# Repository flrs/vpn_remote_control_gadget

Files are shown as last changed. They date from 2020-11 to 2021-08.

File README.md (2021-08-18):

# VPN Remote Control Gadget

> Make it easy to be more private on the internet and remote control the VPN settings on your ASUS RT-AC68U router.

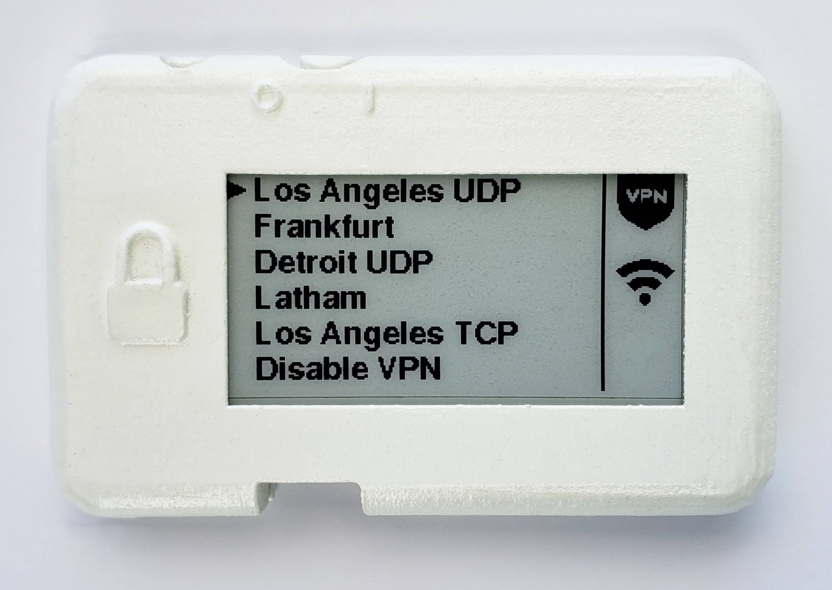
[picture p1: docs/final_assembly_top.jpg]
VPN Remote Control Gadget Case
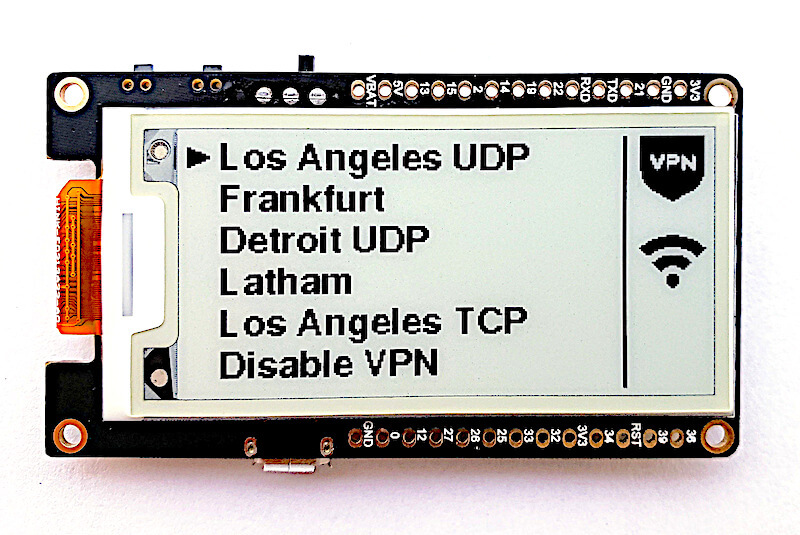
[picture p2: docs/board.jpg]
VPN Remote Control Gadget Without Case


This project creates a remote control from the Arduino-programmed LilyGo TTGO T5 V2.3 ESP32 e-paper microcontroller 
board and a custom-designed 3D-printed case.

## Getting Started

Here is what you will need to build this project yourself:
- ASUS RT-AC68U router, configured to use a VPN of your choice
- LilyGo TTGO T5 V2.3 board
- USB charger and/or small LiPo battery (look for model number 301525)

### Programming the TTGO T5

You can find the Arduino sketch in the [vpn_remote_control_gadget](./arduino/vpn_remote_control_gadget) directory. 

1. Copy this directory into your Arduino sketch directory.
2. Follow the instructions in the 
   [LilyGo repository](https://github.com/Xinyuan-LilyGO/LilyGo-T5-ink-series/tree/acffc2fce8a6d504aa812ce1f9745281bd57a4bc)
   to install Arduino libraries for the TTGO T5 V2.3 board.
3. Install the following Arduino libraries via the Arduino library manager:
   - [ArduinoHttpClient](https://github.com/arduino-libraries/ArduinoHttpClient/tree/7f36561e0bced5458516066ae09636e119cae0ed)
   - [rBASE64](https://github.com/boseji/rBASE64/tree/a127f41eea31d2de7abc91cff4b2d1f4521625ec)
   - [ArduinoJson](https://arduinojson.org/)
   - [StringSplitter](https://github.com/aharshac/StringSplitter/tree/faef239fcea57055ba7bddc35d4a6c47bc05a9b4)
4. Modify the credentials in file [credentials_template.h](./arduino/vpn_remote_control_gadget/credentials_template.h) 
   and rename the file to `credentials.h`.
5. Upload the sketch to the board!

### Printing the Case

Send the file [vpn_control_gadget_assembly_manuf.obj](./cad/manufacturing/vpn_remote_control_gadget_assembly_manuf.obj)
to a 3D printing place of your choice. The case is designed so it can be printed through SLS with PA 12 material and a
rough finish. A [vpn_control_gadget_assembly_manuf.stl](./cad/manufacturing/vpn_remote_control_gadget_assembly_manuf.stl)
file is also available, should your printing place not like `.obj` files.

## Using the Gadget

To select a new VPN server or disconnect from the VPN, turn the TTGO T5 on using the slider on top of the case. Then,
select a VPN with the button next to the slider. Once the checkmark appears in the bottom right of the screen, the
request to change the VPN has been sent to the router. Now, you can turn off the gadget with the slider again. This 
helps to save battery. 

Thanks to the e-paper display your choice will remain visible even when the device powers off.

## Code Overview

The code on the Arduino talks to the ASUS router via POST requests. This is just like how the browser communicates with
the ASUS configuration page when you are logged into the router configuration in your browser.

The code was only tested with RT-AC68U firmware version 3.0.0.4.385_20633. If you use a different firmware, this code
may not longer work without adjustments.

All icons in the UI except for the arrow have been downloaded from [flaticon.com](https://www.flaticon.com) and 
converted to an Arduino-readable file format via the [LCD Image Converter](https://lcd-image-converter.riuson.com).

## CAD Overview

(see also on [Thingiverse](https://www.thingiverse.com/thing:4668495))

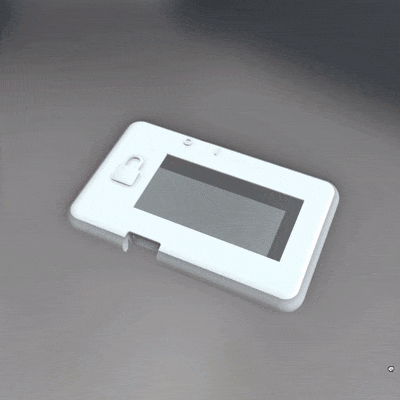
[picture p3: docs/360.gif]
360 degree view of CAD assembly


If you want to modify the case, you can find all CAD design files in the [cad/design](./cad/design) directory. You can
open and edit the files in [FreeCAD](https://www.freecadweb.org/). The files were created in FreeCAD version 0.19-22492.

### Mechanical Features

**Lid:** The case has a sliding lid on the back through which the microcontroller board can be inserted and removed. 
The lid is held in place by a pin. The pin unlocks when the lid is bent outward.

**Buttons:** The case has interfaces to 2 of TTGO T5's buttons. The lid features a cover for the button that is 
connected to channel IO39. The cover is connected to the case by a living hinge, avoiding any additional assembly. 
The case also provides an interface for the board's on/off slider. The slider is a removable part of the assembly, 
but stays in place thanks to a groove in the case's body once the board is assembled.

### Assembly Notes

With the case, the TTGO T5 can be either used with a USB connection alone, or with a small LiPo battery. There is space 
for a 80 mAh battery in the case (search for model number 301525).

There are 6 cylindrical support pins that help the assembly stay in placing during printing. After printing, you need 
to remove these 6 pins to separate the model into its 3 parts. If printed with PA 12, these pins should be easy to cut 
with scissors, a knife, or simply bending until they break. To make sure all components slide and fit neatly, you should
 grind down any leftovers of the pins.

Once all components are separated, push the on/off slider component onto the on/off switch, insert the board into to 
case, and slide the lid shut.

Optionally, the case can be mounted on surfaces by means of double-sided tape.

## Potential Design Improvements

The design presented here is functional. However, based on feedback from the very first 3d print of the gadget 
(see make on [Thingiverse](https://www.thingiverse.com/make:906624)), there are a couple of improvements future makers
may want to take on:

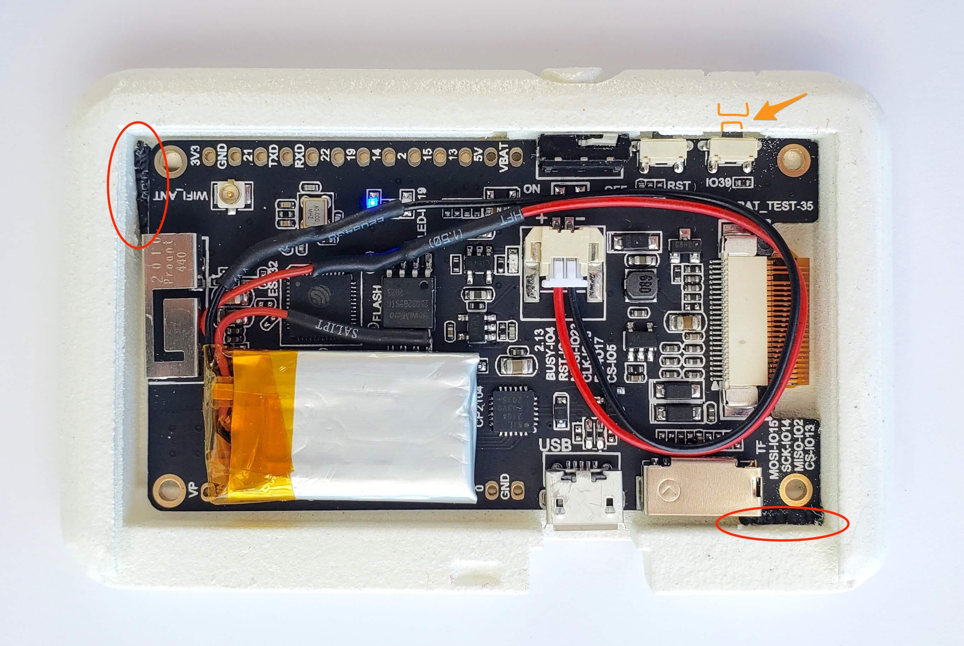
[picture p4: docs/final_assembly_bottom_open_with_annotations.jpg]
VPN Remote Control Gadget bottom, open cover, with annotations


- **Tolerances of part are too large.** During design, I was extra cautious to implement a +0.5 mm tolerance in all directions. 
This creates gaps that are too large, resulting in the PCB in the case sliding around and the slider originally not working. Filling material 
gets the job of fixing the PCB done and makes the slider workable (see red ellipses). Before printing, I 
would advise makers to add about 0.4 mm to the inner walls to restrict lateral movement of the PCB. Also consider that 
this may bring the e-paper screen further off-center, potentially hiding part of the screen.

- **Pushbutton casing component not properly dimensioned.** The gap between the lower side of the case's pushbutton 
component is too far from the top of the actual pushbutton. This results in the user having to press the push button 
in the casing with a lot of force for the actual pushbutton to be actuated. I would advise adding about 0.5 mm to 
the inner-facing part of the push button component in the casing before printing (see orange arrow).

- **USB interface slot slightly misaligned.** The USB interface slot should be positioned a little bit more (about
 0.5 mm) to the left, looking from the bottom of the case, as in the picture above. While the current position works
 for connecting a USB charger, it is slightly off-center.

- **Case cover too thin.** The sliding case cover, while functional, is subjectively too thin. It bends, making it 
hard for the pin that goes into the groove for closing the cover to stay in place. For future iterations, I 
would advise to deepen the groove for closing and to make the pin bigger. I would also advise to increase the 
thickness of the cover. Alternatively, I would add structural elements to the underside of the cover to improve its stiffness.

## Contributing

For questions or feedback, please file an issue here on GitHub. Feel free to open pull requests for any changes you 
think the project could benefit from.

## Credits

Code:
 - Used LilyGO [starter sketch](https://github.com/Xinyuan-LilyGO/LilyGo-T5-ink-series/blob/acffc2fce8a6d504aa812ce1f9745281bd57a4bc/LilyGo_T5_V2.3/LilyGo_T5_V2.3.ino) as a basis for communicating with e-paper display
 - WiFi Error icon, WiFi icon, VPN, and tick icon made by [Freepik](https://www.flaticon.com/authors/freepik) from [www.flaticon.com](https://www.flaticon.com/)
 - Hourglass icon made by [Kiranshastry](https://www.flaticon.com/free-icon/hourglass_709705?term=hourglass&page=1&position=18&related_item_id=709705) from [www.flaticon.com](https://www.flaticon.com/)

CAD:
 - The eye illustration on the back of the lid is part of Samuel Jessurun de Mesquita's print 
   "Zelfportret van alleen de ogen" (public domain, see [here](http://hdl.handle.net/10934/RM0001.COLLECT.209046)).

## License

This project is published under the [MIT License](./LICENSE.md).

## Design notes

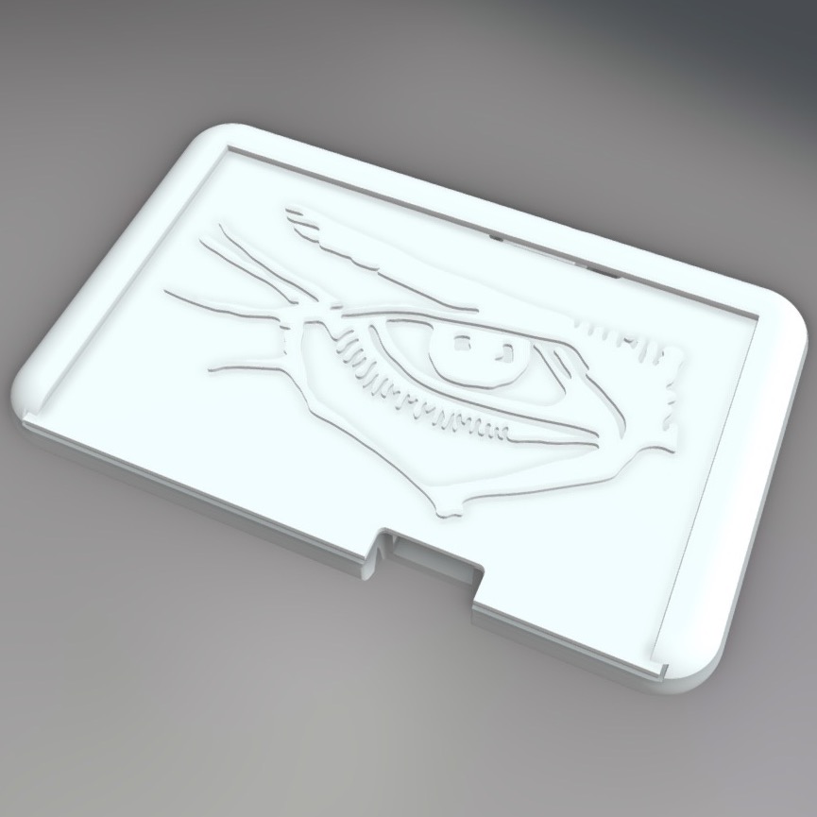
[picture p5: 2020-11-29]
docs/back.jpg

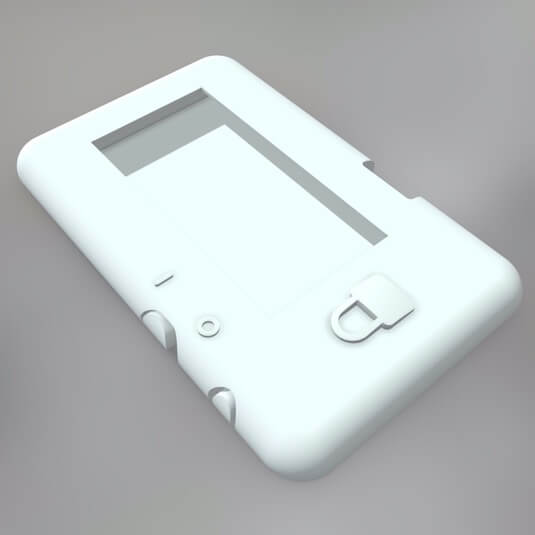
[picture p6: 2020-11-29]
docs/front_smaller.jpg

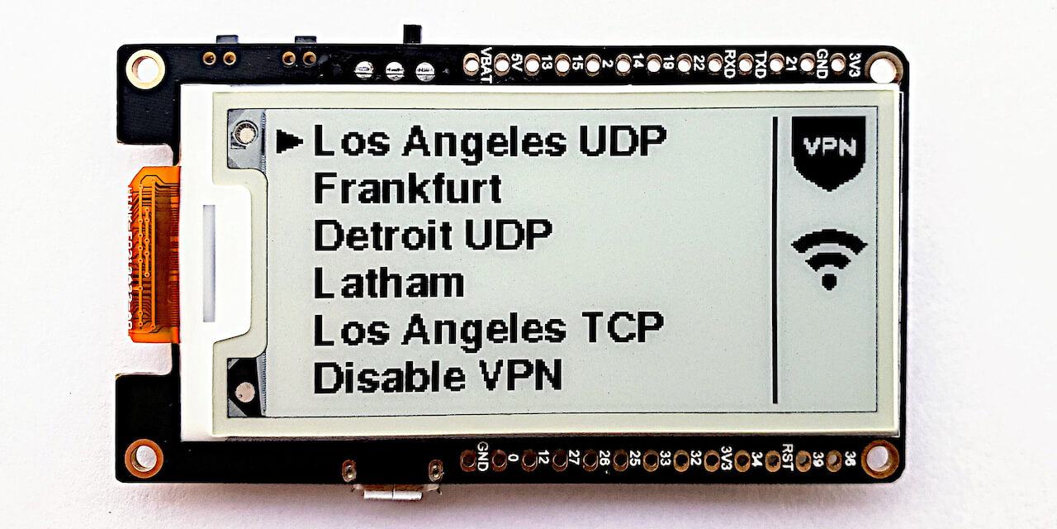
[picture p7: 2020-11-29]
docs/repo_social_preview.jpg

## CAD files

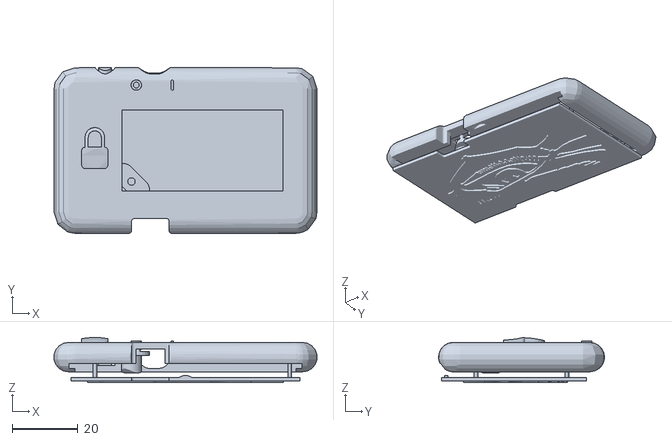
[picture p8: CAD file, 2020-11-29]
cad/manufacturing/vpn_remote_control_gadget_assembly_manuf.obj
80.3 x 50.7 x 13.8

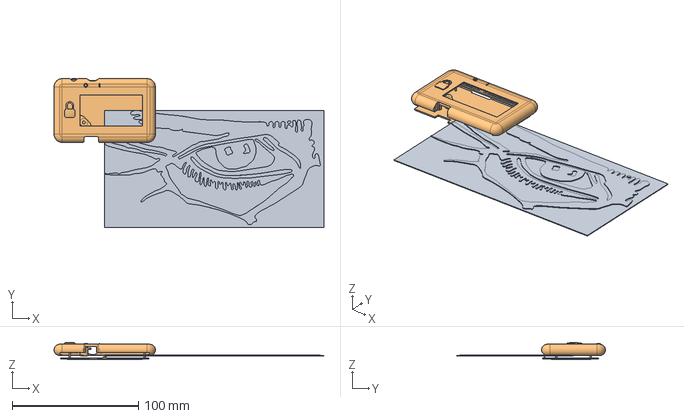
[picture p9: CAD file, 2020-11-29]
cad/design/vpn_remote_control_gadget.FCStd
214.1 x 118.1 x 13.8 mm
eye_origin
assembly_manufacture

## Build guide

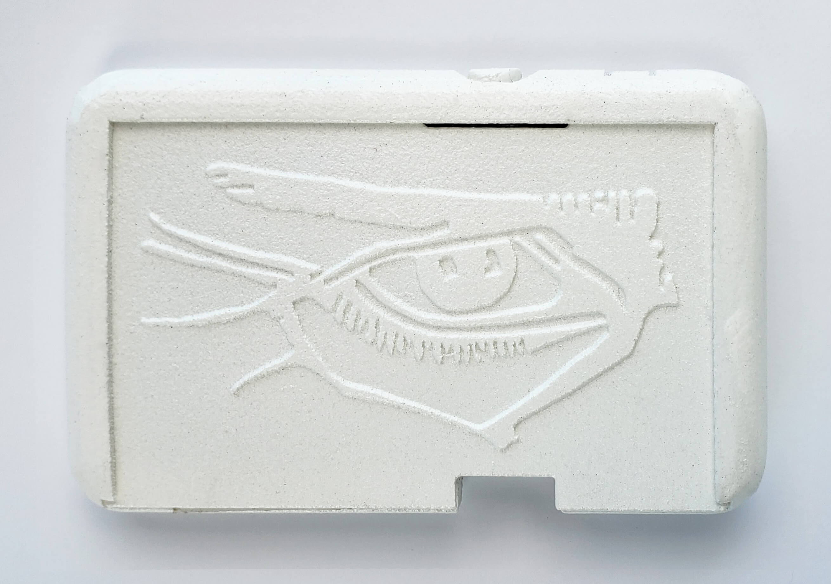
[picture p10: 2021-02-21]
docs/final_assembly_bottom.jpg

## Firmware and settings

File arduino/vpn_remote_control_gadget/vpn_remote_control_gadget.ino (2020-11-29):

#include <GxEPD.h>
#include "SPI.h"
#include <WiFi.h>
#include <ArduinoHttpClient.h>
#include <rBase64.h>
#include <ArduinoJson.h>
#include "StringSplitter.h"
#include "credentials.h"

#include <GxGDEH0213B73/GxGDEH0213B73.h>
#include <Fonts/FreeSansBold9pt7b.h>

#include <GxIO/GxIO_SPI/GxIO_SPI.h>
#include <GxIO/GxIO.h>

#define SPI_MOSI 23
#define SPI_MISO -1
#define SPI_CLK 18

#define ELINK_SS 5
#define ELINK_BUSY 4
#define ELINK_RESET 16
#define ELINK_DC 17

#define BUTTON_PIN 39
#define MAX_CLIENTS 5

GxIO_Class io(SPI, ELINK_SS, ELINK_DC, ELINK_RESET);
GxEPD_Class display(io, ELINK_RESET, ELINK_BUSY);

String client_names[MAX_CLIENTS];
String client_usernames[MAX_CLIENTS];
String client_pws[MAX_CLIENTS];
String client_protos[MAX_CLIENTS];
int client_addresses[MAX_CLIENTS];

String asus_token;
String orig_client_list;

int selected_client = 0;
int connected_client = 0;

unsigned long last_menu_interaction = 0;

WiFiClient wifi;
HttpClient client = HttpClient(wifi, server_address, 80);

const unsigned char arrow[] = {
        0x00, 0x00,
        0xc0, 0x00,
        0xf0, 0x00,
        0xfe, 0x00,
        0xff, 0x80,
        0xff, 0xe0,
        0xff, 0xe0,
        0xff, 0x80,
        0xfe, 0x00,
        0xf0, 0x00,
        0xc0, 0x00,
        0x00, 0x00
};

const unsigned char vpn[] = {
        0xff, 0xff, 0xff, 0xfe,
        0xff, 0xff, 0xff, 0xfe,
        0xff, 0xff, 0xff, 0xfe,
        0xff, 0xff, 0xff, 0xfe,
        0xff, 0xff, 0xff, 0xfe,
        0xff, 0xff, 0xff, 0xfe,
        0xff, 0xff, 0xff, 0xfe,
        0xff, 0xff, 0xff, 0xfe,
        0xff, 0xff, 0xff, 0xfe,
        0xf9, 0xc8, 0x37, 0xbe,
        0xf9, 0xc8, 0x13, 0x9e,
        0xf8, 0x8b, 0x91, 0x9e,
        0xfc, 0x98, 0x10, 0x9e,
        0xfc, 0x18, 0x30, 0x1e,
        0xfe, 0x3b, 0xf2, 0x1e,
        0xfe, 0x3b, 0xf3, 0x1e,
        0xff, 0x7b, 0xf3, 0x9e,
        0x7f, 0xff, 0xff, 0xfe,
        0x7f, 0xff, 0xff, 0xfe,
        0x7f, 0xff, 0xff, 0xfe,
        0x7f, 0xff, 0xff, 0xfc,
        0x3f, 0xff, 0xff, 0xfc,
        0x3f, 0xff, 0xff, 0xf8,
        0x1f, 0xff, 0xff, 0xf8,
        0x0f, 0xff, 0xff, 0xf0,
        0x07, 0xff, 0xff, 0xe0,
        0x03, 0xff, 0xff, 0xc0,
        0x00, 0xff, 0xff, 0x00,
        0x00, 0x3f, 0xfc, 0x00,
        0x00, 0x1f, 0xf0, 0x00,
        0x00, 0x07, 0xe0, 0x00,
        0x00, 0x01, 0x80, 0x00
};

const unsigned char tick[] = {
        0x00, 0x0f, 0xf0, 0x00,
        0x00, 0x7f, 0xfe, 0x00,
        0x01, 0xff, 0xff, 0x80,
        0x03, 0xff, 0xff, 0xc0,
        0x07, 0xff, 0xff, 0xe0,
        0x0f, 0xff, 0xff, 0xf0,
        0x1f, 0xff, 0xff, 0xf8,
        0x3f, 0xff, 0xff, 0xfc,
        0x3f, 0xff, 0xff, 0xfc,
        0x7f, 0xff, 0xfe, 0xfe,
        0x7f, 0xff, 0xf8, 0x7e,
        0x7f, 0xff, 0xf0, 0x3e,
        0xff, 0xff, 0xe0, 0x3f,
        0xff, 0xff, 0xc0, 0x7f,
        0xfe, 0x7f, 0x80, 0xff,
        0xfc, 0x3f, 0x01, 0xff,
        0xfc, 0x1e, 0x03, 0xff,
        0xfc, 0x0c, 0x07, 0xff,
        0xfe, 0x00, 0x0f, 0xff,
        0xff, 0x00, 0x1f, 0xff,
        0x7f, 0x80, 0x3f, 0xfe,
        0x7f, 0xc0, 0x7f, 0xfe,
        0x7f, 0xe0, 0xff, 0xfe,
        0x3f, 0xf1, 0xff, 0xfc,
        0x3f, 0xff, 0xff, 0xf8,
        0x1f, 0xff, 0xff, 0xf8,
        0x0f, 0xff, 0xff, 0xf0,
        0x07, 0xff, 0xff, 0xe0,
        0x03, 0xff, 0xff, 0xc0,
        0x01, 0xff, 0xff, 0x00,
        0x00, 0x7f, 0xfe, 0x00,
        0x00, 0x0f, 0xf0, 0x00
};

const unsigned char hourglass[] = {
        0x07, 0xff, 0xff, 0xe0,
        0x07, 0xff, 0xff, 0xe0,
        0x07, 0xff, 0xff, 0xe0,
        0x00, 0x00, 0x00, 0x00,
        0x01, 0xff, 0xff, 0x80,
        0x01, 0xff, 0xff, 0x80,
        0x01, 0xff, 0xff, 0x80,
        0x01, 0xff, 0xff, 0x80,
        0x01, 0xff, 0xff, 0x80,
        0x01, 0xff, 0xff, 0x80,
        0x01, 0xff, 0xff, 0x00,
        0x00, 0x7f, 0xfe, 0x00,
        0x00, 0x3f, 0xfc, 0x00,
        0x00, 0x1f, 0xf8, 0x00,
        0x00, 0x0f, 0xf0, 0x00,
        0x00, 0x07, 0xe0, 0x00,
        0x00, 0x07, 0xe0, 0x00,
        0x00, 0x0f, 0xf0, 0x00,
        0x00, 0x1f, 0xf8, 0x00,
        0x00, 0x3f, 0xfc, 0x00,
        0x00, 0xff, 0xfe, 0x00,
        0x01, 0xff, 0xff, 0x80,
        0x01, 0xff, 0xff, 0x80,
        0x01, 0xff, 0xff, 0x80,
        0x01, 0xff, 0xff, 0x80,
        0x01, 0xff, 0xff, 0x80,
        0x01, 0xff, 0xff, 0x80,
        0x01, 0xff, 0xff, 0x80,
        0x00, 0x00, 0x00, 0x00,
        0x07, 0xff, 0xff, 0xe0,
        0x07, 0xff, 0xff, 0xe0,
        0x07, 0xff, 0xff, 0xe0
};

const unsigned char wifi_signal[] = {
        0x00, 0x00, 0x00, 0x00,
        0x00, 0x00, 0x00, 0x00,
        0x00, 0x00, 0x00, 0x00,
        0x00, 0x07, 0xe0, 0x00,
        0x00, 0x7f, 0xfe, 0x00,
        0x03, 0xff, 0xff, 0xc0,
        0x0f, 0xff, 0xff, 0xf0,
        0x1f, 0xff, 0xff, 0xf8,
        0x7f, 0xff, 0xff, 0xfc,
        0xff, 0xf0, 0x0f, 0xff,
        0x7f, 0x80, 0x01, 0xfe,
        0x3e, 0x00, 0x00, 0x7c,
        0x1c, 0x00, 0x00, 0x38,
        0x00, 0x1f, 0xf8, 0x10,
        0x00, 0x7f, 0xfe, 0x00,
        0x00, 0xff, 0xff, 0x00,
        0x03, 0xff, 0xff, 0x80,
        0x01, 0xff, 0xff, 0x00,
        0x00, 0xfc, 0x3e, 0x00,
        0x00, 0x70, 0x0c, 0x00,
        0x00, 0x20, 0x00, 0x00,
        0x00, 0x00, 0x00, 0x00,
        0x00, 0x03, 0xc0, 0x00,
        0x00, 0x07, 0xe0, 0x00,
        0x00, 0x07, 0xe0, 0x00,
        0x00, 0x07, 0xe0, 0x00,
        0x00, 0x07, 0xe0, 0x00,
        0x00, 0x03, 0xc0, 0x00,
        0x00, 0x01, 0x80, 0x00,
        0x00, 0x00, 0x00, 0x00,
        0x00, 0x00, 0x00, 0x00,
        0x00, 0x00, 0x00, 0x00
};

const unsigned char wifi_error[]{
        0x00, 0x00, 0x00, 0x00,
        0x00, 0x00, 0x00, 0x00,
        0x00, 0x00, 0x00, 0x00,
        0x00, 0x00, 0x00, 0x00,
        0x00, 0x00, 0x00, 0x00,
        0x00, 0xff, 0xf0, 0x00,
        0x03, 0xff, 0xfe, 0x00,
        0x0f, 0xff, 0xff, 0x80,
        0x3f, 0xff, 0xff, 0xc0,
        0x7f, 0xff, 0xff, 0xe0,
        0xff, 0xc0, 0x1f, 0xf0,
        0x7e, 0x00, 0x07, 0xe0,
        0x3c, 0x00, 0x01, 0xc0,
        0x10, 0x3f, 0xc0, 0xc0,
        0x00, 0xff, 0xf0, 0x00,
        0x01, 0xff, 0xf2, 0x04,
        0x03, 0xff, 0xe7, 0x0e,
        0x01, 0xff, 0xcf, 0x9f,
        0x00, 0xf0, 0x67, 0xfe,
        0x00, 0x40, 0x33, 0xfc,
        0x00, 0x00, 0x01, 0xf8,
        0x00, 0x06, 0x01, 0xf8,
        0x00, 0x0f, 0x83, 0xfc,
        0x00, 0x1f, 0x87, 0xfe,
        0x00, 0x1f, 0x87, 0x9e,
        0x00, 0x0f, 0x83, 0x0c,
        0x00, 0x0f, 0x00, 0x00,
        0x00, 0x00, 0x00, 0x00,
        0x00, 0x00, 0x00, 0x00,
        0x00, 0x00, 0x00, 0x00,
        0x00, 0x00, 0x00, 0x00,
        0x00, 0x00, 0x00, 0x00
};


bool connect_to_network() {
    WiFi.begin(ssid, passphrase);

    Serial.print("Establishing connection to WiFi..");
    unsigned long start_connect = millis();
    while (WiFi.status() != WL_CONNECTED && (millis() - start_connect) < 15000) {
        delay(500);
        Serial.print(".");
    }
    if (WiFi.status() != WL_CONNECTED) {
        Serial.println("error!");
        return false;
    } else {
        Serial.println("done!");
        return true;
    }
}

bool get_auth_token() {
    Serial.print("Getting auth token...");
    rbase64.encode(login_credentials);
    String postData = "login_authorization=";
    postData.concat(rbase64.result());
    client.beginRequest();
    client.post("/login.cgi");
    client.sendHeader(HTTP_HEADER_CONTENT_TYPE, "application/x-www-form-urlencoded");
    client.sendHeader(HTTP_HEADER_USER_AGENT, "asusrouter-Android-DUTUtil-1.0.0.3.58-163");
    client.sendHeader(HTTP_HEADER_CONTENT_LENGTH, postData.length());
    client.endRequest();
    client.write((const byte *) postData.c_str(), postData.length());

    int statusCode = client.responseStatusCode();
    String response = client.responseBody();

    if (statusCode == 200) {
        DynamicJsonDocument doc(128);
        DeserializationError error = deserializeJson(doc, response);
        if (error) {
            Serial.println("error in deserialization.");
            asus_token = "";
            return false;
        } else {
            Serial.println("done!");
            asus_token = (const char *) doc["asus_token"];
        }
    } else {
        asus_token = "";
        Serial.print("error in request. Return status code: ");
        Serial.println(statusCode);
        return false;
    }
    return true;
}

bool get_server_info() {
    Serial.print("Getting server info...");
    String postData = "hook=nvram_get(vpnc_clientlist)";
    String auth_header = "asus_token=";
    auth_header.concat(asus_token);

    client.beginRequest();
    client.post("/appGet.cgi");
    client.sendHeader(HTTP_HEADER_CONTENT_TYPE, "application/x-www-form-urlencoded");
    client.sendHeader(HTTP_HEADER_USER_AGENT, "asusrouter-Android-DUTUtil-1.0.0.3.58-163");
    client.sendHeader("COOKIE", auth_header);
    client.sendHeader(HTTP_HEADER_CONTENT_LENGTH, postData.length());
    client.endRequest();
    client.write((const byte *) postData.c_str(), postData.length());

    int statusCode = client.responseStatusCode();
    String response = client.responseBody();

    String client_list = "";
    if (statusCode == 200) {
        DynamicJsonDocument doc(512);
        DeserializationError error = deserializeJson(doc, response);
        if (error) {
            Serial.println("error in deserialization.");
            return false;
        } else {
            Serial.println("done!");
            orig_client_list = (const char *) doc["vpnc_clientlist"];
            String client_list = orig_client_list;
            orig_client_list.replace("&#62", ">");
            orig_client_list.replace("&#60", "<");

            client_list.replace("&#62", "¦");
            client_list.replace("&#60", "|");

            StringSplitter *client_list_splitter = new StringSplitter(client_list, '|', -1);
            int no_clients = client_list_splitter->getItemCount();

            for (int client_ct = 0; client_ct < no_clients; client_ct++) {
                String client_item = client_list_splitter->getItemAtIndex(client_ct);
                StringSplitter *client_item_splitter = new StringSplitter(client_item, '¦', -1);
                int no_client_infos = client_item_splitter->getItemCount();

                client_names[client_ct] = client_item_splitter->getItemAtIndex(0);
                client_names[client_ct] = client_names[client_ct].substring(0, client_names[client_ct].length() - 1);

                client_protos[client_ct] = client_item_splitter->getItemAtIndex(1);
                client_protos[client_ct] = client_protos[client_ct].substring(0, client_protos[client_ct].length() - 1);
                client_protos[client_ct].toLowerCase();
                client_addresses[client_ct] = (client_item_splitter->getItemAtIndex(2)).toInt();

                client_usernames[client_ct] = client_item_splitter->getItemAtIndex(3);
                client_usernames[client_ct] = client_usernames[client_ct].substring(0,
                                                                                    client_usernames[client_ct].length() -
                                                                                    1);
                client_pws[client_ct] = client_item_splitter->getItemAtIndex(4);
            }
        }
    } else {
        Serial.print("error in request. Return status code: ");
        Serial.println(statusCode);
        return false;
    }
    return true;
}


bool set_server(int server_id, bool deactivate) {
    Serial.print("Now setting server...");
    String query = "";

    query.concat("current_page=Advanced_VPNClient_Content.asp");
    query.concat("&next_page=Advanced_VPNClient_Content.asp");
    query.concat("&modified=0");
    query.concat("&flag=background");
    query.concat("&action_mode=apply");
    query.concat("&action_script=restart_vpncall");
    query.concat("&action_wait=3");
    query.concat("&preferred_lang=EN");
    query.concat("&firmver=3.0.0.4");
    query.concat("&vpnc_dnsenable_x=1");
    query.concat("&vpnc_proto=");
    if (!deactivate) {
        query.concat(client_protos[server_id]);
    }
    query.concat("&vpnc_clientlist=");

    String orig_client_list_changes = orig_client_list;
    orig_client_list_changes.replace(" ", "+");
    orig_client_list_changes = URLEncoder.encode(orig_client_list_changes);
    orig_client_list_changes.replace("%2B", "+");
    query.concat(orig_client_list_changes);
    query.concat("&vpnc_type=PPTP");
    query.concat("&vpn_client_unit=");
    if (!deactivate) {
        query.concat(client_addresses[server_id]);
    }
    for (int i = 0; i < MAX_CLIENTS; i++) {
        String var_name = "vpn_client";
        var_name.concat(i + 1);
        var_name.concat("_username");
        query.concat("&");
        query.concat(var_name);
        query.concat("=");
        query.concat(client_usernames[i]);

        var_name = "vpn_client";
        var_name.concat(i + 1);
        var_name.concat("_password");
        query.concat("&");
        query.concat(var_name);
        query.concat("=");
        query.concat(client_pws[i]);
    }
    query.concat("&vpn_clientx_eas=");
    if (!deactivate) {
        String eas = String(client_addresses[server_id]);
        eas.concat("%2C");
        query.concat(eas);
    }

    String options_list = "";
    for (int i = 0; i < MAX_CLIENTS; i++) {
        options_list.concat("<auto");
    }
    query.concat("&vpnc_pptp_options_x_list=");
    query.concat(URLEncoder.encode(options_list));

    query.concat("&vpnc_des_edit=");
    if (!deactivate) {
        String chosen_client = client_names[server_id];
        chosen_client.replace(" ", "+");
        query.concat(chosen_client);
    }

    query.concat("&selPPTPOption=auto");

    String postData;

    String auth_header = "asus_token=";
    auth_header.concat(asus_token);
    client.beginRequest();
    client.post("/start_apply.htm");
    client.sendHeader(HTTP_HEADER_CONTENT_TYPE, "application/x-www-form-urlencoded");
    client.sendHeader(HTTP_HEADER_USER_AGENT, "asusrouter-Android-DUTUtil-1.0.0.3.58-163");
    client.sendHeader("COOKIE", auth_header);
    client.sendHeader("Accept-Encoding", "gzip, deflate");
    client.sendHeader("Accept", "*/*");
    client.sendHeader("Connection", "keep-alive");
    client.sendHeader(HTTP_HEADER_CONTENT_LENGTH, query.length());
    client.endRequest();
    client.write((const byte *) query.c_str(), query.length());

    int status_code = client.responseStatusCode();
    String response = client.responseBody();
    if (status_code == 200) {
        if (!deactivate) {
            Serial.print("done and connected to ");
            Serial.print(client_names[server_id]);
            Serial.println("!");
        } else {
            Serial.println("done and disconnected from VPN.");
        }
        connected_client = server_id;
        return true;
    } else {
        Serial.print("error, error code: ");
        Serial.println(status_code);
        return false;
    }
}

void draw_menu(bool partial_update) {
    if (!partial_update) {
        for (int i = 0; i < MAX_CLIENTS; i++) {
            display.setCursor(15, 15 + i * 20);
            display.println(client_names[i]);
        }
        display.setCursor(15, 15 + MAX_CLIENTS * 20);
        display.println("Disable VPN");
    } else {
        display.fillRect(0, 0, 15, display.height(), GxEPD_WHITE);
    }
    display.drawBitmap(arrow, 0, 15 + selected_client * 20 - 11, 12, 12, GxEPD_BLACK);
    if (!partial_update) {
        display.update();
    } else {
        display.updateWindow(0, 0, 15, display.height(), true);
    }
    last_menu_interaction = millis();
}

void setup() {
    pinMode(BUTTON_PIN, INPUT);
    Serial.begin(115200);
    Serial.println();
    Serial.println("Starting up.");
    SPI.begin(SPI_CLK, SPI_MISO, SPI_MOSI, ELINK_SS);
    display.init();

    display.setRotation(3);
    display.fillScreen(GxEPD_WHITE);
    display.setTextColor(GxEPD_BLACK);
    display.setFont(&FreeSansBold9pt7b);
    display.update();

    display.fillRect(display.width() - 40, 0, 2, display.height(), GxEPD_BLACK);
    display.updateWindow(display.width() - 40, 0, 2, display.height(), true);

    display.drawBitmap(vpn, display.width() - 32, 0, 32, 32, GxEPD_BLACK);
    display.updateWindow(display.width() - 32, 0, 32, 32, true);

    if (connect_to_network() && get_auth_token()) {
        display.drawBitmap(wifi_signal, display.width() - 32, display.height() / 2 - 16, 32, 32, GxEPD_BLACK);
    } else {
        display.drawBitmap(wifi_error, display.width() - 32, display.height() / 2 - 16, 32, 32, GxEPD_BLACK);
    }
    display.updateWindow(display.width() - 32, 36, 32, 32, true);

    if (asus_token.length() == 0) {
        Serial.println("Startup error: Error fetching router credentials.");
        display.drawBitmap(wifi_error, display.width() - 32, display.height() / 2 - 16, 32, 32, GxEPD_BLACK);
        display.updateWindow(display.width() - 32, 36, 32, 32, true);

    } else {
        get_server_info();
        draw_menu(false);
        Serial.println("Startup successful.");
    }

}


void loop() {
    if (!digitalRead(BUTTON_PIN)) {
        selected_client += 1;
        if (selected_client == MAX_CLIENTS + 1) {
            selected_client = 0;
        }
        while (!digitalRead(BUTTON_PIN)) {
            delay(20);
        }
        draw_menu(true);
    }
    if (millis() - last_menu_interaction > 2000 && connected_client != selected_client) {
        display.drawBitmap(hourglass, display.width() - 32 - 1, display.height() - 32 - 1, 32, 32, GxEPD_BLACK);
        display.updateWindow(display.width() - 32 - 1, display.height() - 32 - 1, 32, 32, true);
        if (set_server(selected_client, selected_client == MAX_CLIENTS)) {
            display.drawBitmap(tick, display.width() - 32 - 1, display.height() - 32 - 1, 32, 32, GxEPD_BLACK);
            display.updateWindow(display.width() - 32 - 2, display.height() - 32 - 1, 33, 32, true);
            if (selected_client != MAX_CLIENTS) {
                display.drawBitmap(vpn, display.width() - 32 - 1, 0, 32, 32, GxEPD_BLACK);
            } else {
                display.fillRect(display.width() - 32 - 1, 0, 32, 32, GxEPD_WHITE);
            }
            display.updateWindow(display.width() - 32 - 1, 0, 32, 32, true);
        }
    }
}
